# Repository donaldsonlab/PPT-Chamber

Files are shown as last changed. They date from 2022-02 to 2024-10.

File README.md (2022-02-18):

# Partner Preference Test Chamber

This repository contains 3D models, created in Solidworks, and fabrication files for designing and constructing a Partner Preference Test (PPT) chamber. This is divided into three
sections, two of which provide mounting holes to tether animals. When not in use, the tether holes and slots on the sides may be covered up by a clip-on hole cover. This cover
can slide from the slot to the hole, covering one at a time.

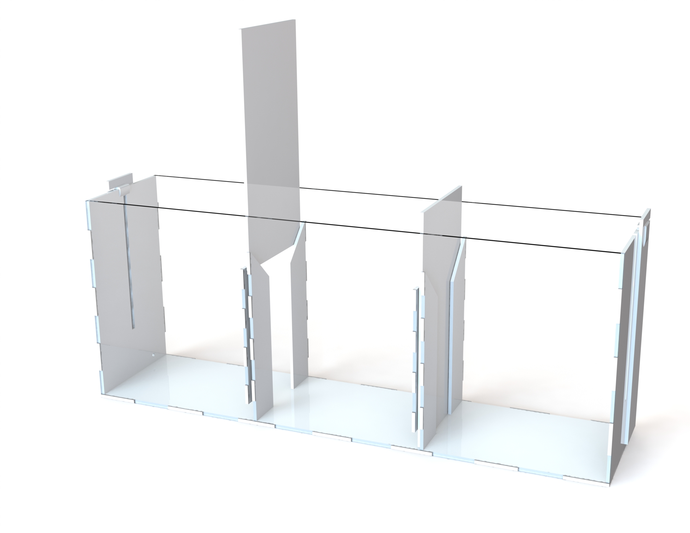
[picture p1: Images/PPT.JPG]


The walls of this chamber are laser cut out of clear 3/16" acrylic sheets, painted matte white where needed, and assembled using plastic cement. The files used on the laser 
cutters are located in the [DXF](/DXF) directory. To optimize the nesting of parts on as few acrylic sheets as possible, we use an open source software called 
[Deepnest](https://deepnest.io/). We 3D print the hole cover clips on a Zortrax M200 Plus FDM printer with PLA, ABS, or Z-ULTRAT filament. The .STL file for this is in the 
[STL](/STL) folder along with a [PPT_cornerBracket](/STL/PPT_cornerBracket.STL) file, which is just used to hold the corners of the chamber together while gluing.

|       Bill of Materials      |
--------------------------------
|Part|Description|Quantity|
----------------------|------------------------------------------------------------------------|-|
PPT_Floor             |Laser cut [PPT_Floor.dxf](/DXF/PPT_Floor.dxf)                           |1|
PPT_LongWall          |Laser cut [PPT_LongWall.dxf](/DXF/PPT_LongWall.dxf)                     |2|
PPT_SideWall          |Laser cut [PPT_SideWall.dxf](/DXF/PPT_SideWall.dxf)                     |2|
PPT_InsertGuide_Large |Laser cut [PPT_InsertGuide_Large.dxf](/DXF/PPT_InsertGuide_Large.dxf)   |4|
PPT_InsertGuide_Small |Laser cut [PPT_InsertGuide_Small.dxf](/DXF/PPT_InsertGuide_Small.dxf)   |4|
PPT_HoleCover         |Laser cut [PPT_HoleCover.DXF](/DXF/PPT_HoleCover.DXF)                   |2|
PPT_HoleCover_Clip    |3D printed PLA/ABS [PPT_HoleCover_Clip.stl](/STL/PPT_HoleCover_Clip.stl)|2|
Plastic Cement        |Plastruct Plastic Weld or IPS Weld-On 3 Acrylic Plastic Cement          |<1|
Matte White Paint     |[Krylon Fusion All-In-One Spray Paint, Matte, White, 12 oz.](https://www.walmart.com/ip/Krylon-Fusion-All-In-One-Spray-Paint-Matte-White-12-oz/678882687)|<1|
PPT_CornerBracket     |Optional 3D printed PLA/ABS [PPT_CornerBracket](/STL/PPT_CornerBracket) |4|

The brand of acrylic cement is not important, as long as it can hold the acrylic pieces together. Similarly, the brand of paint is unimportant and can either be *matte* or *flat*, although matte finishes can typically withstand more cleaning.

**Note:** If the wall 
thickness is adjusted, the 3D models and .DXF files must also be modified. This can be done in the text file, [PPTequations.txt](PPTequations.txt), which contains equations
used for each Solidworks part. Simply change the "WallThickness" and/or "FloorThickness" to the desired value and rebuild or refresh the part files. This can also be done with the
other variables in PPTequations.txt if wanting to modify the width, height, or depth of the PPT chamber. Changing this file will change dimensions in every part file.

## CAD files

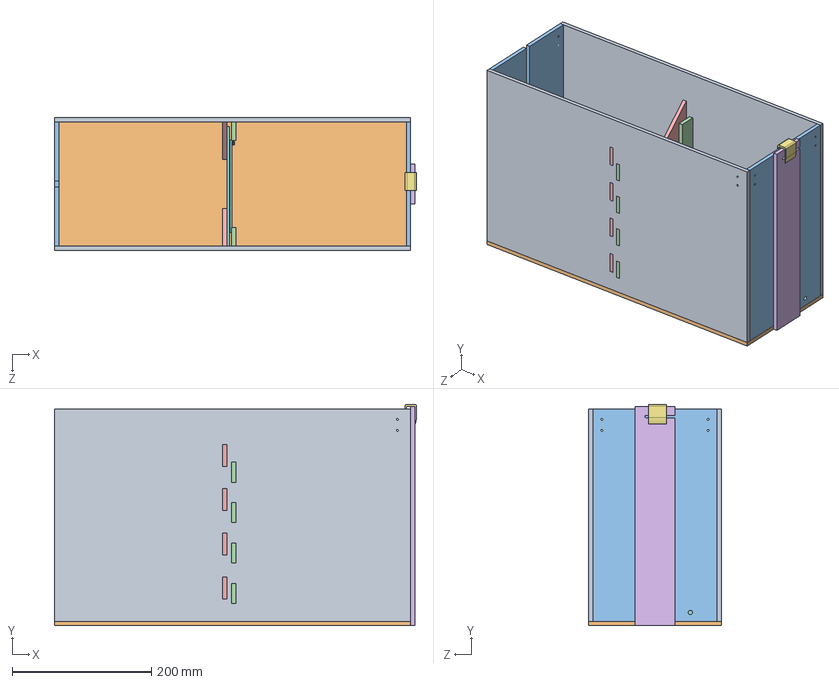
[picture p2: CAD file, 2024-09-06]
Main - 2 Chamber PPT/PPT_FullAssembly.SLDASM
519.5 x 317.9 x 190.5 mm
PPT_Floor
PPT_LongWall x 2
PPT_SideWall x 2
PPT_InsertGuide_Small x 2
PPT_InsertGuide_Large x 2

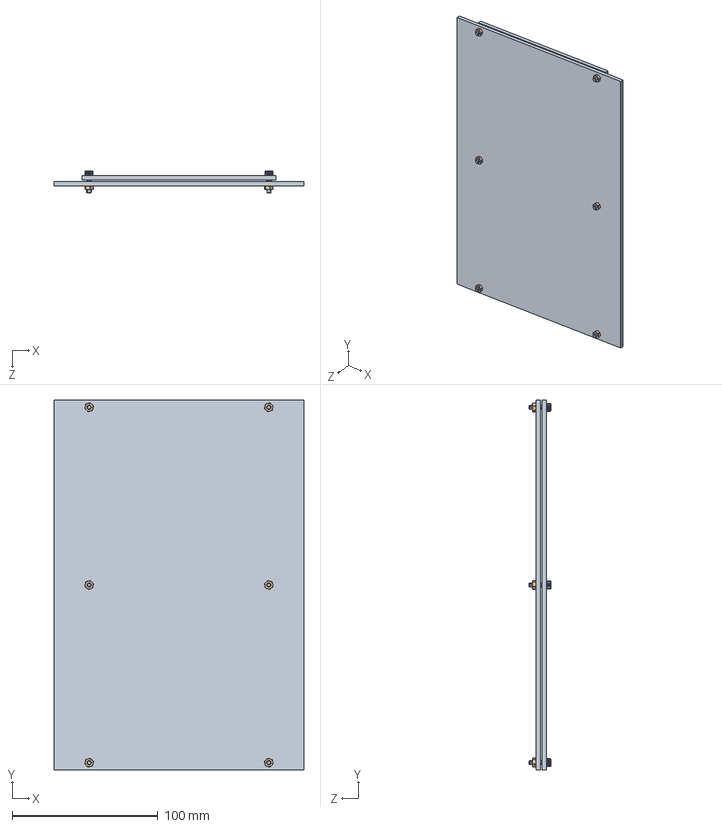
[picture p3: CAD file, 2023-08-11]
Main/Dividers/mesh_divider_assem.SLDASM
171.4 x 254.0 x 15.0 mm
mesh_divider x 2
M3_nut x 6
M3x12 x 6

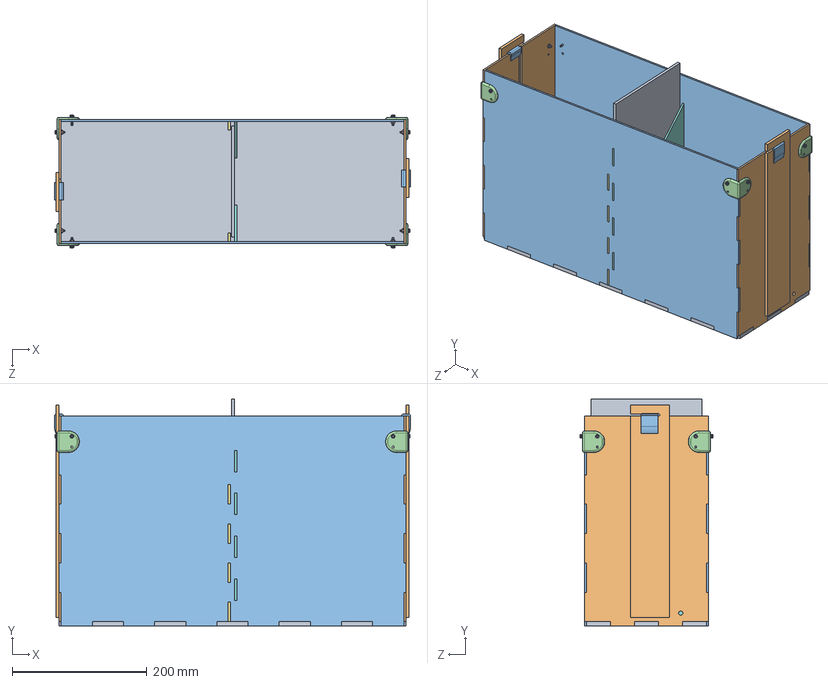
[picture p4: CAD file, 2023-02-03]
2-Chamber/PPT2_Assem.SLDASM
527.9 x 336.5 x 196.5 mm
PPT2_Base
PPT2_SideWall x 2
PPT2_Long_Wall x 2
wall_bracket x 4
M3_nut x 8
M3x12 x 8
PPT2_InsertGuide_Small x 2
PPT2_InsertGuide_Large x 2
PPT2_Insert
PPT2_holeCover x 2
PPT2_holeCover_clip x 2

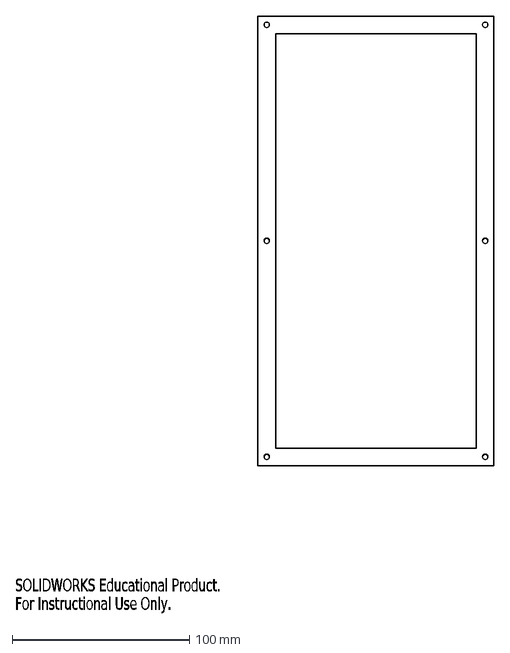
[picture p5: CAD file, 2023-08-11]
Main/Dividers/mesh_divider_fullCut.DXF
SOLIDWORKS Educational Product.
For Instructional Use Only.

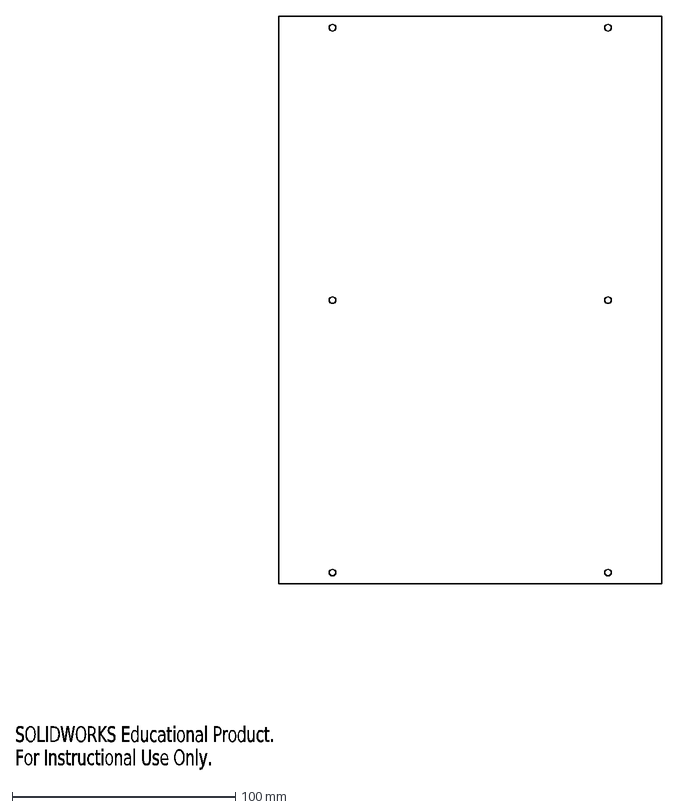
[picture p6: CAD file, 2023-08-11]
Main/Dividers/mesh_divider_fullDefault.DXF
SOLIDWORKS Educational Product.
For Instructional Use Only.

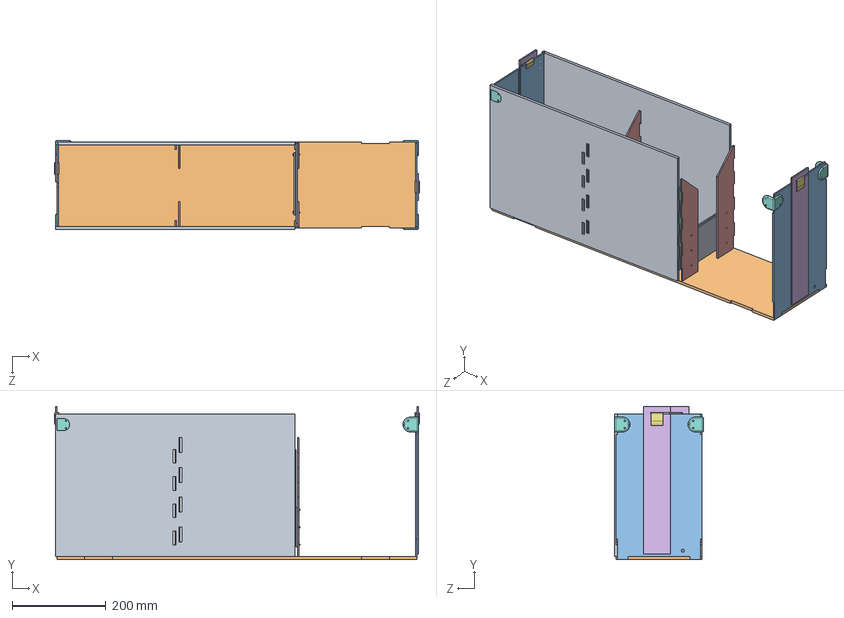
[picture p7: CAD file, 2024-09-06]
Main/PPT_FullAssembly.SLDASM
778.7 x 327.0 x 190.5 mm
PPT_Floor
PPT_LongWall x 2
PPT_SideWall x 2
PPT_InsertGuide_Small x 4
PPT_InsertGuide_Large x 4
PPT_holeCover x 2
PPT_holeCover_clip x 2
wall_bracket x 4
mesh_divider x 2
M3_nut x 6
M3x12 x 6

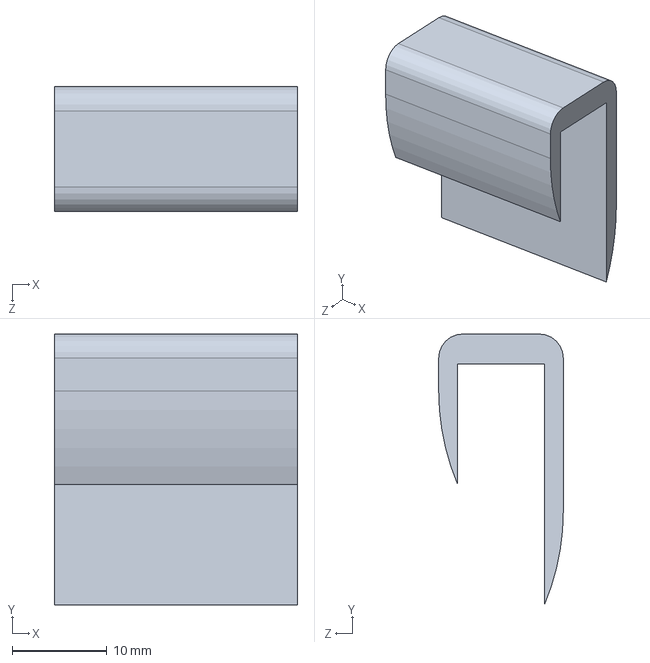
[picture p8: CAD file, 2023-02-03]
2-Chamber/PPT2_holeCover_clip.SLDPRT
25.7 x 28.6 x 13.1 mm

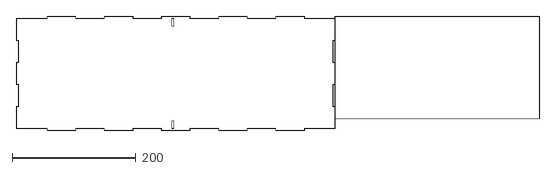
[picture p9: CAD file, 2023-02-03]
2-Chamber/printing/quarter_inch.DXF
844.9 x 184.5

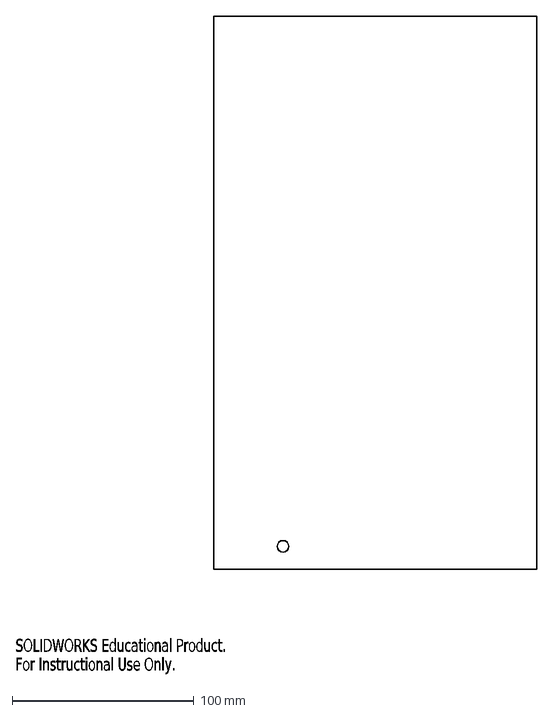
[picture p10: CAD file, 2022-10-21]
Laser Cutting/PPT_SideWall_dark.DXF
SOLIDWORKS Educational Product.
For Instructional Use Only.

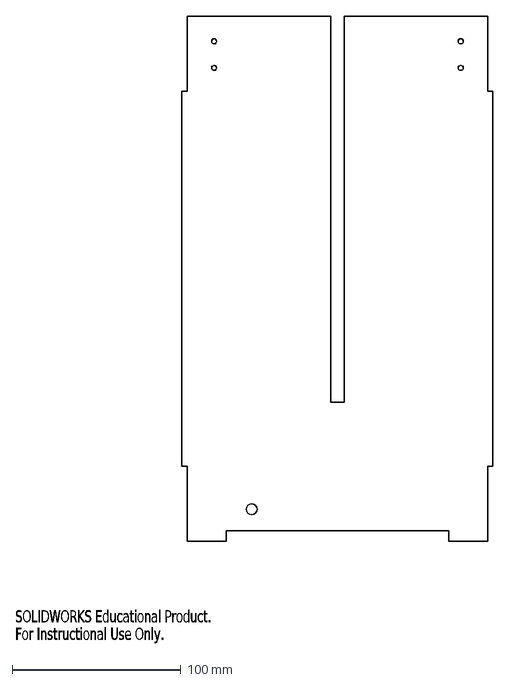
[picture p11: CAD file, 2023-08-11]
Main - 2 Chamber PPT/Cutting/PPT_SideWall.DXF
SOLIDWORKS Educational Product.
For Instructional Use Only.

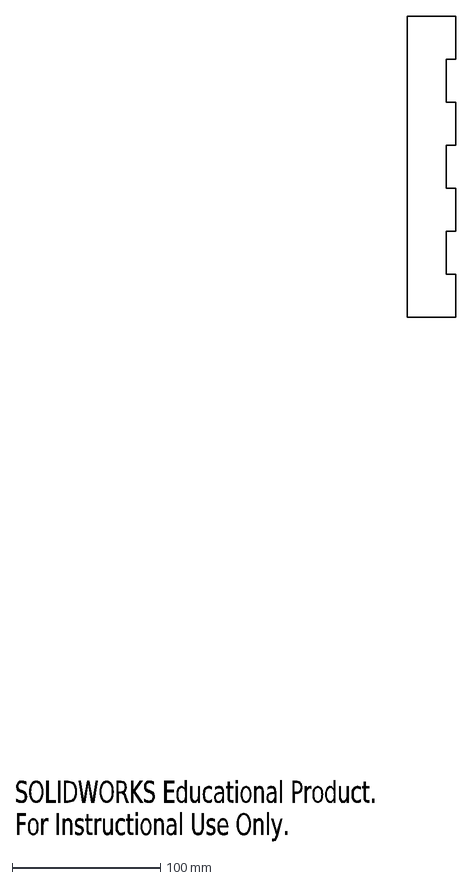
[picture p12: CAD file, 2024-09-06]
Main - 2 Chamber PPT/drawing files 20231101/PPT_InsertGuide_Small.DXF
SOLIDWORKS Educational Product.
For Instructional Use Only.

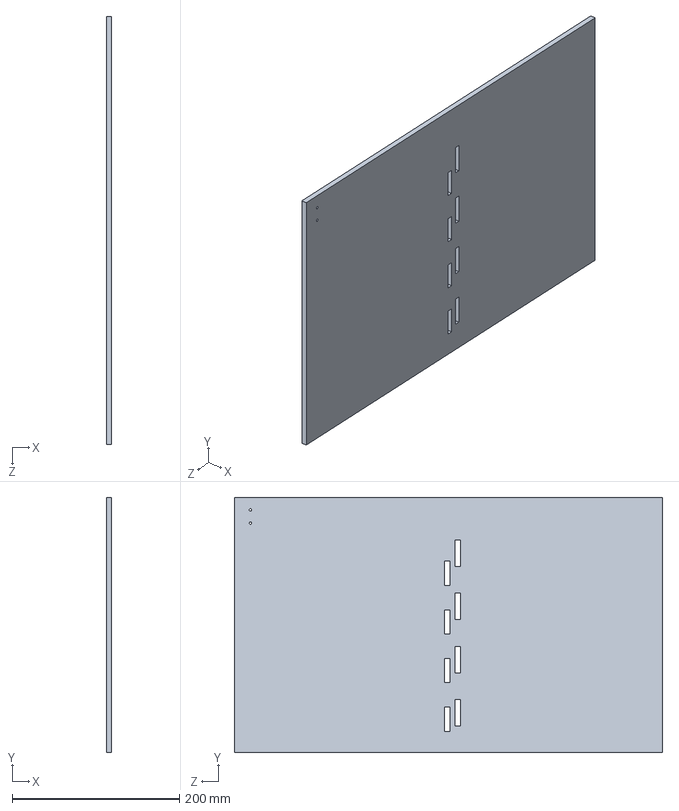
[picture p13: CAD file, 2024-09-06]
Main - 2 Chamber PPT/PPT_LongWall.SLDPRT
6.35 x 304.8 x 511.2 mm

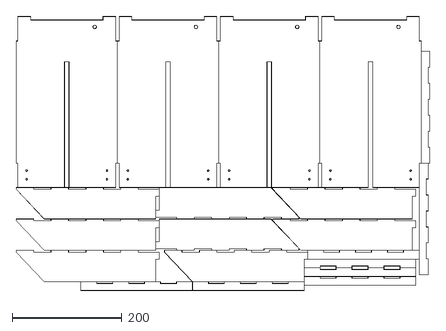
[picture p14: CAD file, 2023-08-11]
Main/Cutting/opaque_cuts.DXF
752.8 x 498.8

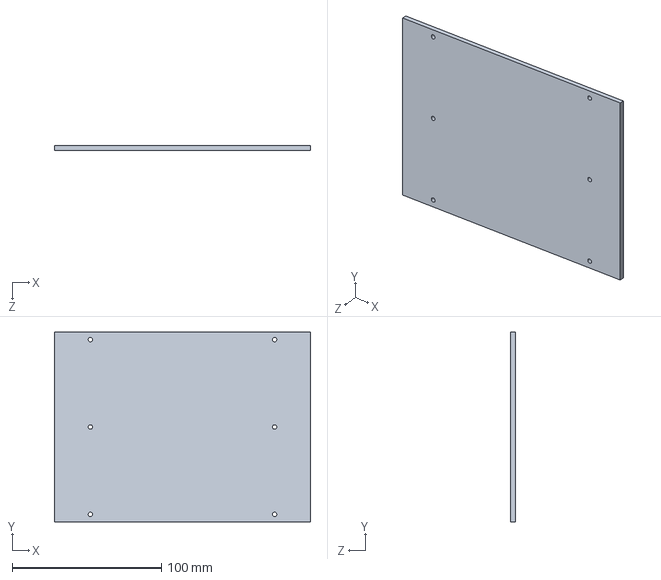
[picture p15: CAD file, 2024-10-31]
Main/Dividers/5 in_climbing_divider.SLDPRT
171.4 x 127.0 x 3.17 mm

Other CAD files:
Main/Dividers/Climbing Wall Drawings/Two_Thirds_climbing_ladder.DXF
Main/PPT_SideWall.SLDPRT
STL/PPT_cornerBrace_oppo.STL
2-Chamber/PPT2_Base.SLDPRT
2-Chamber/PPT2_Base.SLDDRW
2-Chamber/PPT2_Insert.SLDDRW
2-Chamber/PPT2_Insert.SLDPRT
2-Chamber/PPT2_InsertGuide_Large.SLDDRW
2-Chamber/PPT2_InsertGuide_Large.SLDPRT
2-Chamber/PPT2_InsertGuide_Small.SLDDRW
2-Chamber/PPT2_InsertGuide_Small.SLDPRT
2-Chamber/PPT2_Long_Wall.SLDDRW
2-Chamber/PPT2_Long_Wall.SLDPRT
2-Chamber/PPT2_SideWall.SLDDRW
2-Chamber/PPT2_SideWall.SLDPRT
2-Chamber/PPT2_holeCover.SLDDRW
2-Chamber/PPT2_holeCover.SLDPRT
2-Chamber/printing/PPT2_Base.DXF
2-Chamber/printing/PPT2_Insert.DXF
2-Chamber/printing/PPT2_InsertGuide_Large.DXF
2-Chamber/printing/PPT2_InsertGuide_Small.DXF
2-Chamber/printing/PPT2_Long_Wall.DXF
2-Chamber/printing/PPT2_SideWall.DXF
2-Chamber/printing/PPT2_holeCover.DXF
2-Chamber/printing/eigth_inch.DXF
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

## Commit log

2022-02-18 Initial Release
    [PPT_Floor.DXF, PPT_Floor.SLDPRT, PPT_FullAssembly.SLDASM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]
2022-02-18 Updated organization and rendering
    [PPT_Floor.SLDPRT, PPT_FullAssembly.SLDASM, PPT_Insert.SLDPRT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]
2022-02-18 Updated naming convention
    [PPT_FullAssembly.SLDASM, PPT_holeCover_clip.SLDPRT]
2022-07-01 end of week
    [PPT_Floor.SLDPRT, PPT_FullAssembly.SLDASM, PPT_Insert.SLDPRT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]
2022-11-23 Added a 2-chamber variant
    [M3_nut.SLDPRT, M3x12.SLDPRT, M3x16.SLDPRT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]
2023-02-03 end of week - created 2 chamber PPT designs as well as configuration on 3 chamber design for smooth edges instead of puzzle piece edges
    [M3_nut.SLDPRT, M3x12.SLDPRT, PPT2_Assem.SLDASM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]
2023-07-24 End of Work - Ryan Cameron
    [PPT_FullAssembly.SLDASM]
2024-06-27 6/27 update
    [PPT_Floor.DXF, PPT_Insert.DXF, PPT_InsertGuide_Large.DXF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]
2024-09-06 2 Chamber PPT
    [20231108_print.DXF, 20231108_print2.DXF, 20231117_PPT_SideWall_2.DXF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]
2024-10-31 climbing walls
    [5 in_climbing_divider.DXF, 5 in_climbing_divider.SLDPRT, 5_in_climbing_ladder.DXF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]
